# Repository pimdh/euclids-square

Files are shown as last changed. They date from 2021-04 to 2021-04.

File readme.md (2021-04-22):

# Euclid's Square

**THIS IS A WORK IN PROGRESS**

A drum sequencer and sampler based on layering multiple Euclidean rythms. Both firmware and PCB design files are open source licensed under the Creative Commons Attribution 4.0 International License.

## Hardware
It runs on a STM32F722 microcontroller on a custom PCB board.

## Software
The drum machine in written in embedded bare-metal Rust, based on the RTIC framework.

## Samples
Currently, the sampler using the following samples, all in the public domain:
- Hihat https://freesound.org/people/TheFlakesMaster/sounds/399897/
- Snare https://freesound.org/people/alexthegr81/sounds/212208/
- Kick https://freesound.org/people/Mattc90/sounds/351917/

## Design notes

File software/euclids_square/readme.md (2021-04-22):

# Euclid's Square Firmware

Embedded Rust running on a STM32F722. Based on RTIC.

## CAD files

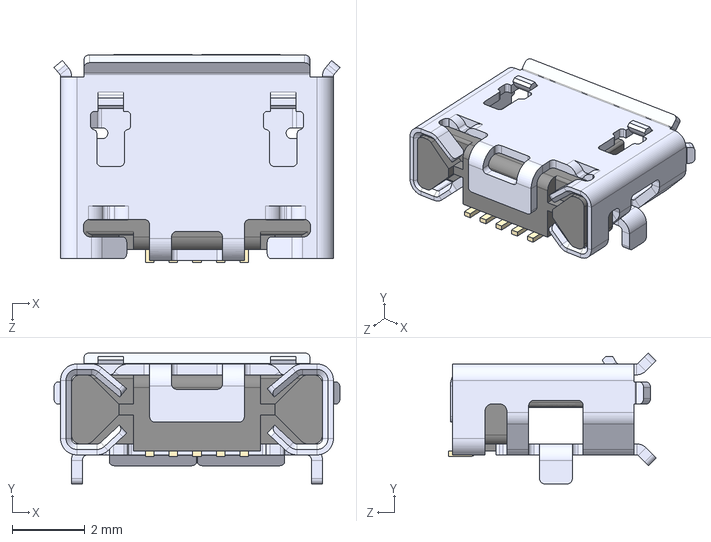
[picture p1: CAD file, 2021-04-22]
hardware/components/10118193-0001LF/10118193-0001LF.step
7.86 x 3.60 x 5.71 mm

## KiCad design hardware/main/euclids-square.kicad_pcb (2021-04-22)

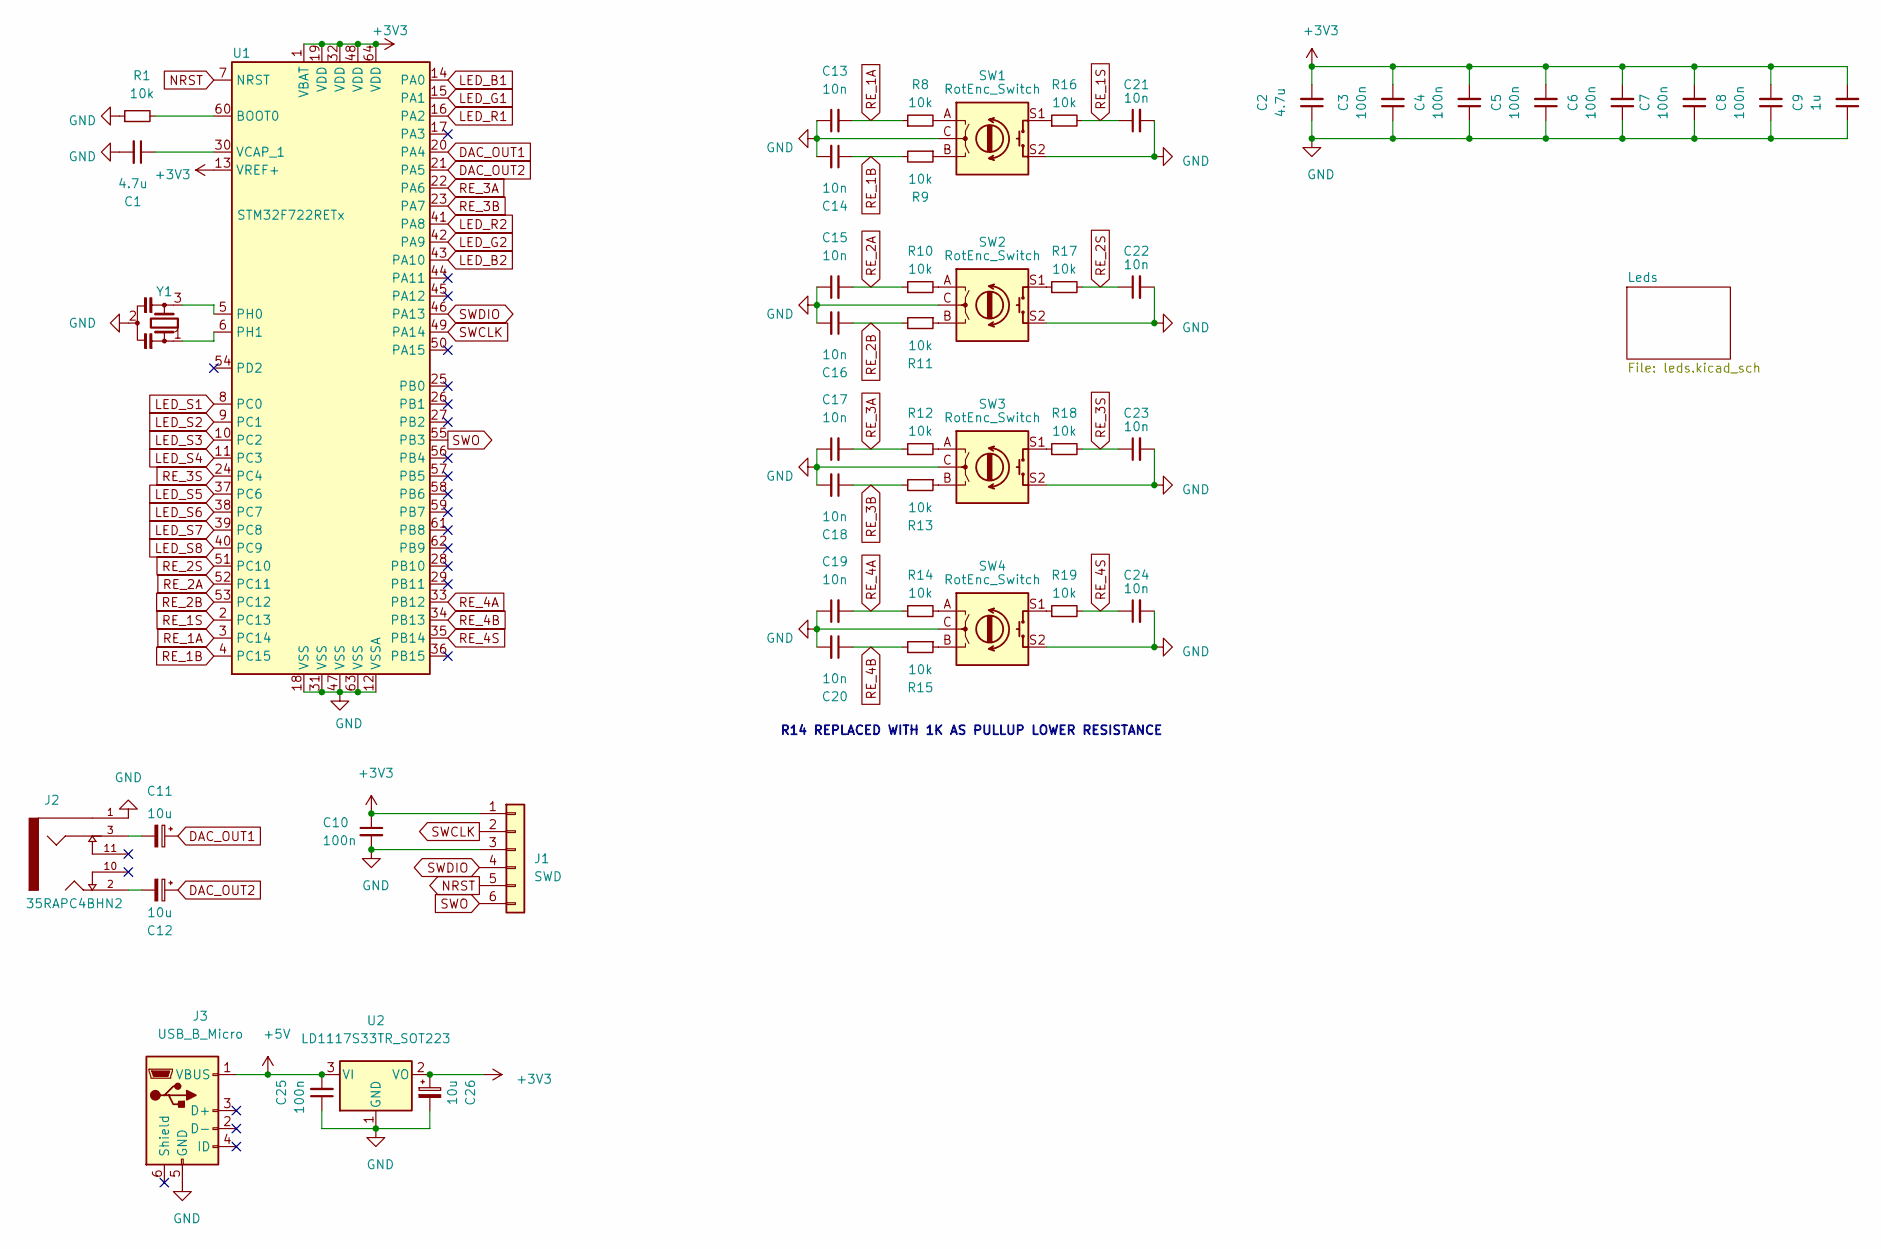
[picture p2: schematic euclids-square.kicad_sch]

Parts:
C1, C2: 4.7u; C_0603_1608Metric; Farnell 3013399
C3, C4, C5, C6, C7, C8, C10, C25: 100n; C_0603_1608Metric; Farnell 2581045
C9: 1u; C_0603_1608Metric; Farnell 3013384
C11, C12, C26: 10u; CP_Elec_4x5.4; Farnell 2611355
C13, C14, C15, C16, C17, C18, C19, C20, C21, C22, C23, C24: 10n; C_0603_1608Metric; Farnell 2496828
J1: SWD; PinHeader_1x06_P2.54mm_Vertical
J2: 35RAPC4BHN2; SWITCHCRAFT_35RAPC4BHN2
J3: USB_B_Micro; USB_Micro-B_Amphenol_10118194_Horizontal
R1, R8, R9, R10, R11, R12, R13, R14, R15, R16, R17, R18, R19: 10k; R_0603_1608Metric; Farnell 2670595
SW1, SW2, SW3, SW4: RotEnc_Switch; RotaryEncoder_Alps_EC12E-Switch_Vertical_H20mm; Farnell 2663527
U1: STM32F722RETx; LQFP-64_10x10mm_P0.5mm; Farnell 3365373
U2: LD1117S33TR_SOT223; SOT-223-3_TabPin2; Farnell 1202826
Y1: Resonator_Small; Resonator_SMD-3Pin_3.2x1.3mm; Farnell 3501598

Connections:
+3V3: C2.2, C3.2, C4.2, C5.2, C6.2, C7.2, C8.2, C9.2, C10.1, C26.1, J1.1, U1.1 (VBAT), U1.13 (VREF+), U1.19 (VDD), U1.32 (VDD), U1.48 (VDD), U1.64 (VDD), U2.2 (VO)
+5V: C25.2, J3.1 (VBUS), U2.3 (VI)
DAC_OUT1: C11.1, U1.20 (PA4)
DAC_OUT2: C12.1, U1.21 (PA5)
GND: C1.2, C2.1, C3.1, C4.1, C5.1, C6.1, C7.1, C8.1, C9.1, C10.2, C13.1, C14.2, C15.1, C16.2, C17.1, C18.2, C19.1, C20.2, C21.2, C22.2, C23.2, C24.2, C25.1, C26.2, J1.3, J2.1, J3.5 (GND), R1.1, SW1.C, SW1.S2, SW2.C, SW2.S2, SW3.C, SW3.S2, SW4.C, SW4.S2, U1.12 (VSSA), U1.18 (VSS), U1.31 (VSS), U1.47 (VSS), U1.63 (VSS), U2.1 (GND), Y1.2; also elsewhere on the board
LED_B1: U1.14 (PA0); also elsewhere on the board
LED_B2: U1.43 (PA10); also elsewhere on the board
LED_G1: U1.15 (PA1); also elsewhere on the board
LED_G2: U1.42 (PA9); also elsewhere on the board
LED_R1: U1.16 (PA2); also elsewhere on the board
LED_R2: U1.41 (PA8); also elsewhere on the board
LED_S1: U1.8 (PC0); also elsewhere on the board
LED_S2: U1.9 (PC1); also elsewhere on the board
LED_S3: U1.10 (PC2); also elsewhere on the board
LED_S4: U1.11 (PC3); also elsewhere on the board
LED_S5: U1.37 (PC6); also elsewhere on the board
LED_S6: U1.38 (PC7); also elsewhere on the board
LED_S7: U1.39 (PC8); also elsewhere on the board
LED_S8: U1.40 (PC9); also elsewhere on the board
NRST: J1.5, U1.7 (NRST)
unnamed: C1.1, U1.30 (VCAP_1)
unnamed: C11.2, J2.3
unnamed: C12.2, J2.2
unnamed: R1.2, U1.60 (BOOT0)
unnamed: R8.2, SW1.A
unnamed: R9.1, SW1.B
unnamed: R10.2, SW2.A
unnamed: R11.1, SW2.B
unnamed: R12.2, SW3.A
unnamed: R13.1, SW3.B
unnamed: R14.2, SW4.A
unnamed: R15.1, SW4.B
unnamed: R16.1, SW1.S1
unnamed: R17.1, SW2.S1
unnamed: R18.1, SW3.S1
unnamed: R19.1, SW4.S1
unnamed: U1.5 (PH0), Y1.3
unnamed: U1.6 (PH1), Y1.1
RE_1A: C13.2, R8.1, U1.3 (PC14)
RE_1B: C14.1, R9.2, U1.4 (PC15)
RE_1S: C21.1, R16.2, U1.2 (PC13)
RE_2A: C15.2, R10.1, U1.52 (PC11)
RE_2B: C16.1, R11.2, U1.53 (PC12)
RE_2S: C22.1, R17.2, U1.51 (PC10)
RE_3A: C17.2, R12.1, U1.22 (PA6)
RE_3B: C18.1, R13.2, U1.23 (PA7)
RE_3S: C23.1, R18.2, U1.24 (PC4)
RE_4A: C19.2, R14.1, U1.33 (PB12)
RE_4B: C20.1, R15.2, U1.34 (PB13)
RE_4S: C24.1, R19.2, U1.35 (PB14)
SWCLK: J1.2, U1.49 (PA14)
SWDIO: J1.4, U1.46 (PA13)
SWO: J1.6, U1.55 (PB3)
no_connect_68: J2.10
no_connect_69: J2.11
no_connect_70: J3.2 (D-)
no_connect_71: J3.3 (D+)
no_connect_72: J3.4 (ID)
no_connect_73: J3.6 (Shield)
no_connect_74: U1.17 (PA3)
no_connect_75: U1.25 (PB0)
no_connect_76: U1.26 (PB1)
no_connect_77: U1.27 (PB2)
no_connect_78: U1.28 (PB10)
no_connect_79: U1.29 (PB11)
no_connect_80: U1.36 (PB15)
no_connect_81: U1.44 (PA11)
no_connect_82: U1.45 (PA12)
no_connect_83: U1.50 (PA15)
no_connect_84: U1.54 (PD2)
no_connect_85: U1.56 (PB4)
no_connect_86: U1.57 (PB5)
no_connect_87: U1.58 (PB6)
no_connect_88: U1.59 (PB7)
no_connect_89: U1.61 (PB8)
no_connect_90: U1.62 (PB9)

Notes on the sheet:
R14 REPLACED WITH 1K AS PULLUP LOWER RESISTANCE

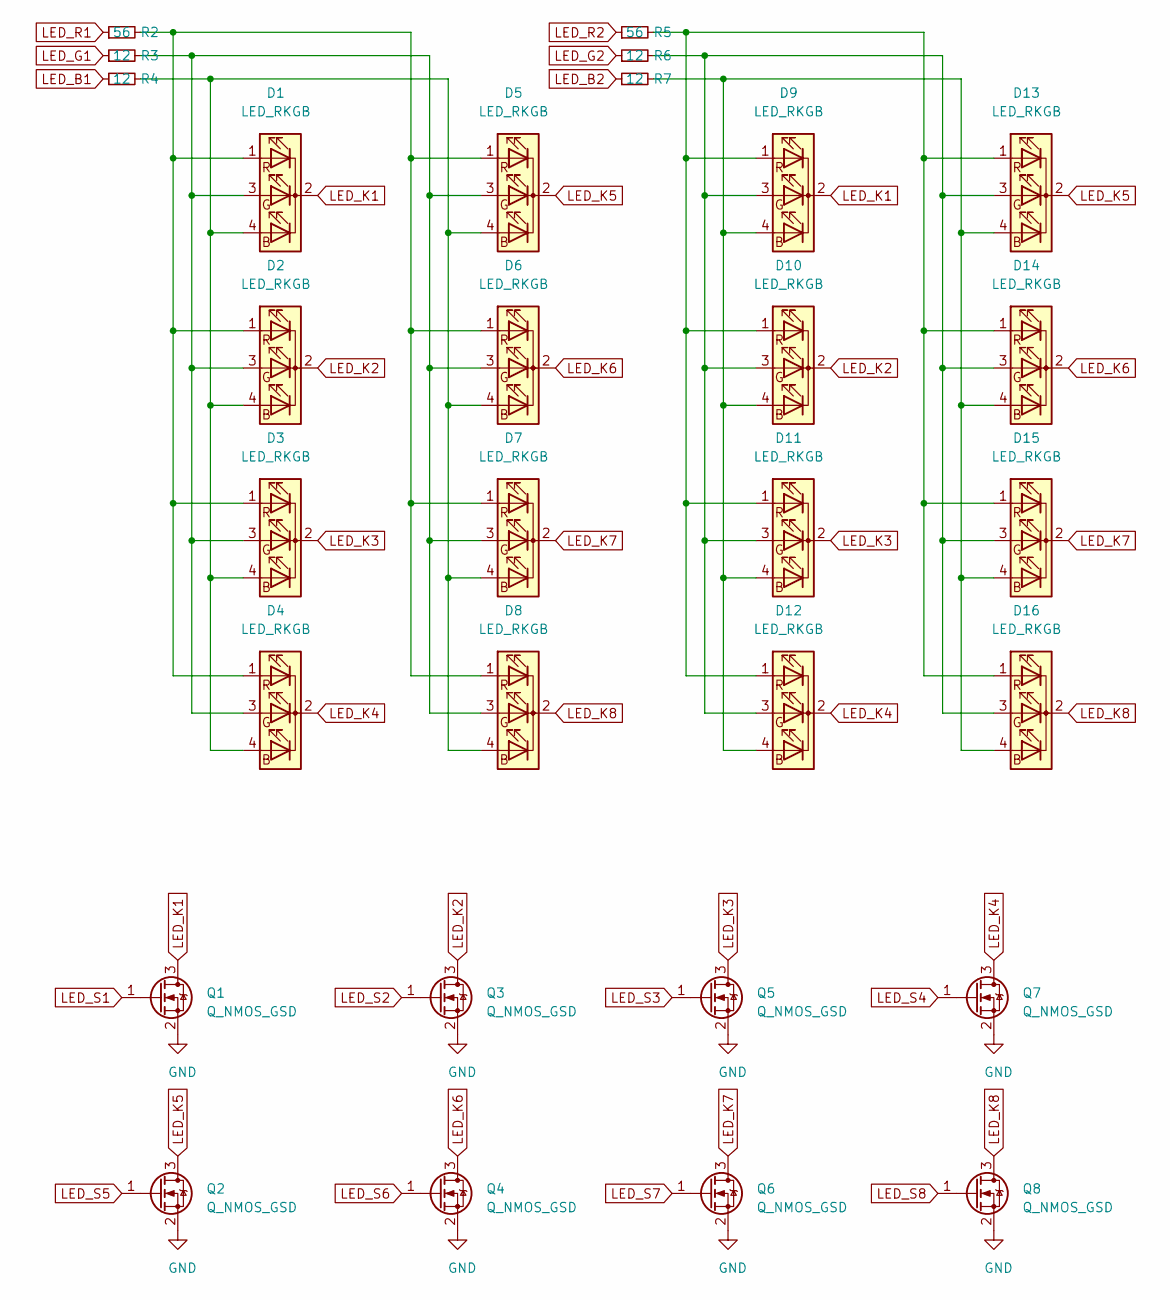
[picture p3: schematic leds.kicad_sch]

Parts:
D1, D2, D3, D4, D5, D6, D7, D8, D9, D10, D11, D12, D13, D14, D15, D16: LED_RKGB; LED_D5.0mm-4_RGB
Q1, Q2, Q3, Q4, Q5, Q6, Q7, Q8: Q_NMOS_GSD; SOT-323_SC-70_Handsoldering; Farnell 3619748
R2, R5: 56; R_0603_1608Metric; Farnell 3540045
R3, R4, R6, R7: 12; R_0603_1608Metric; Farnell 2670626

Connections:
GND: Q1.2 (S), Q2.2 (S), Q3.2 (S), Q4.2 (S), Q5.2 (S), Q6.2 (S), Q7.2 (S), Q8.2 (S); also elsewhere on the board
LED_B1: R4.1; also elsewhere on the board
LED_B2: R7.1; also elsewhere on the board
LED_G1: R3.1; also elsewhere on the board
LED_G2: R6.1; also elsewhere on the board
LED_K1: D1.2 (K), D9.2 (K), Q1.3 (D)
LED_K2: D2.2 (K), D10.2 (K), Q3.3 (D)
LED_K3: D3.2 (K), D11.2 (K), Q5.3 (D)
LED_K4: D4.2 (K), D12.2 (K), Q7.3 (D)
LED_K5: D5.2 (K), D13.2 (K), Q2.3 (D)
LED_K6: D6.2 (K), D14.2 (K), Q4.3 (D)
LED_K7: D7.2 (K), D15.2 (K), Q6.3 (D)
LED_K8: D8.2 (K), D16.2 (K), Q8.3 (D)
LED_R1: R2.1; also elsewhere on the board
LED_R2: R5.1; also elsewhere on the board
LED_S1: Q1.1 (G); also elsewhere on the board
LED_S2: Q3.1 (G); also elsewhere on the board
LED_S3: Q5.1 (G); also elsewhere on the board
LED_S4: Q7.1 (G); also elsewhere on the board
LED_S5: Q2.1 (G); also elsewhere on the board
LED_S6: Q4.1 (G); also elsewhere on the board
LED_S7: Q6.1 (G); also elsewhere on the board
LED_S8: Q8.1 (G); also elsewhere on the board
unnamed: D1.1 (RA), D2.1 (RA), D3.1 (RA), D4.1 (RA), D5.1 (RA), D6.1 (RA), D7.1 (RA), D8.1 (RA), R2.2
unnamed: D1.3 (GA), D2.3 (GA), D3.3 (GA), D4.3 (GA), D5.3 (GA), D6.3 (GA), D7.3 (GA), D8.3 (GA), R3.2
unnamed: D1.4 (BA), D2.4 (BA), D3.4 (BA), D4.4 (BA), D5.4 (BA), D6.4 (BA), D7.4 (BA), D8.4 (BA), R4.2
unnamed: D9.1 (RA), D10.1 (RA), D11.1 (RA), D12.1 (RA), D13.1 (RA), D14.1 (RA), D15.1 (RA), D16.1 (RA), R5.2
unnamed: D9.3 (GA), D10.3 (GA), D11.3 (GA), D12.3 (GA), D13.3 (GA), D14.3 (GA), D15.3 (GA), D16.3 (GA), R6.2
unnamed: D9.4 (BA), D10.4 (BA), D11.4 (BA), D12.4 (BA), D13.4 (BA), D14.4 (BA), D15.4 (BA), D16.4 (BA), R7.2

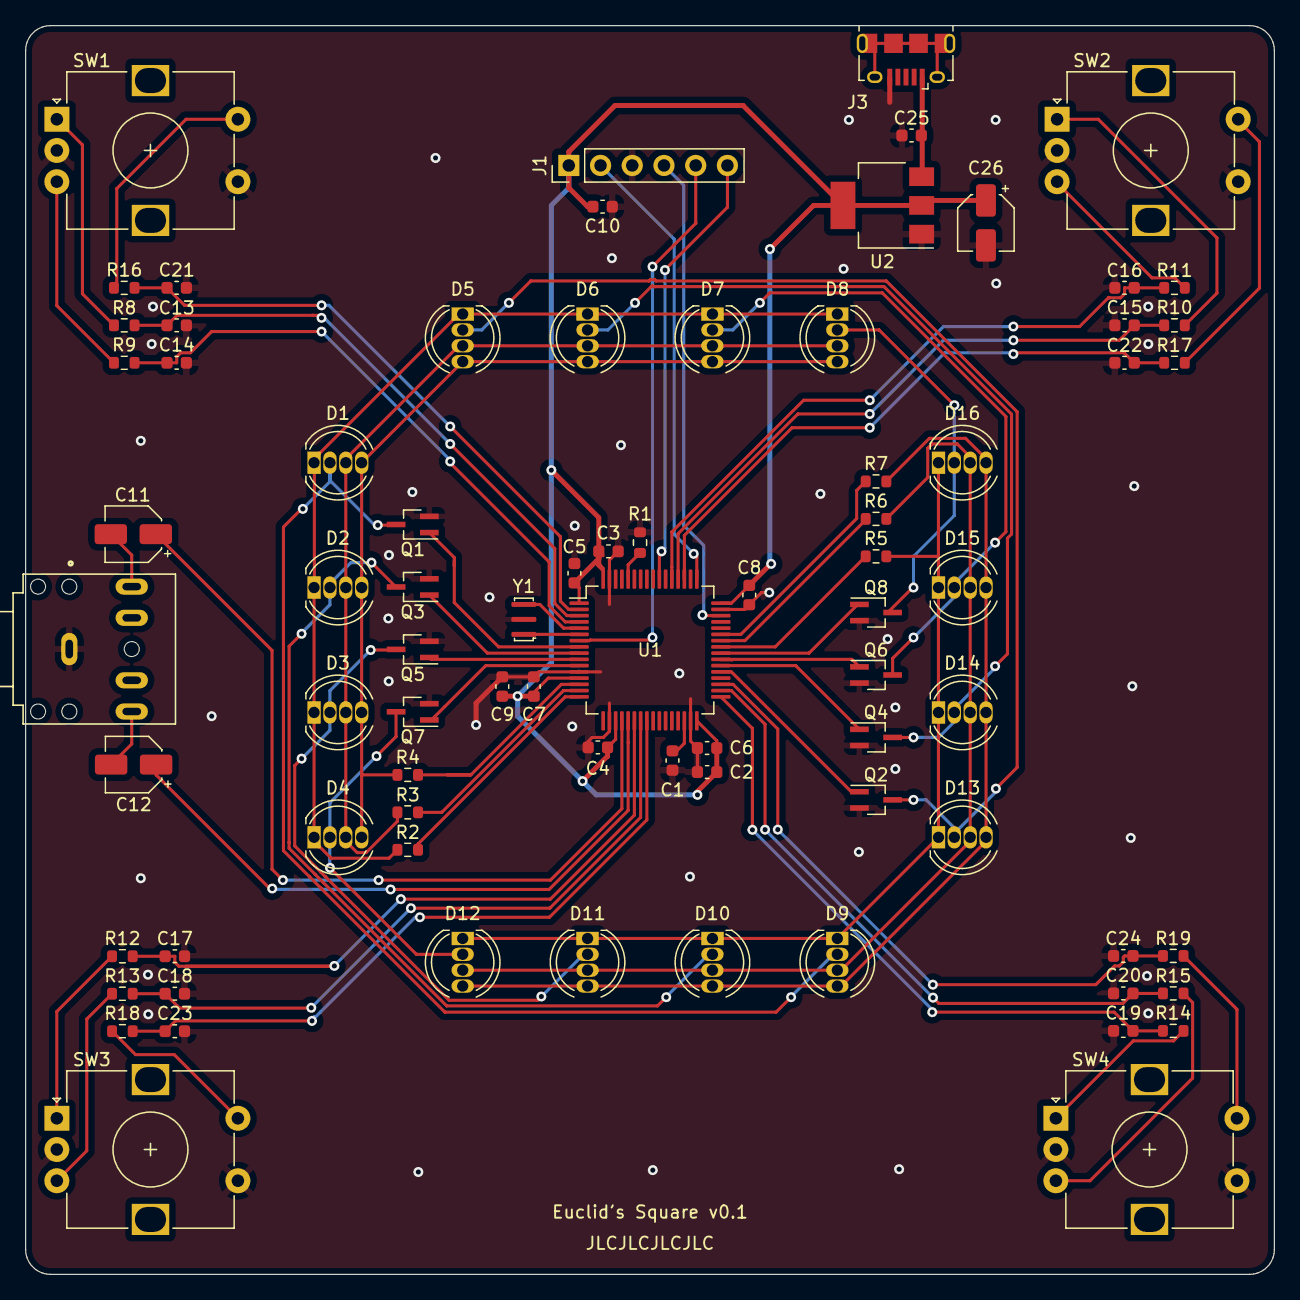
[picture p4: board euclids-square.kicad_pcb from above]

Board: 2 copper layers, 100.0 x 100.0 mm, 79 parts (0 on the bottom side), 67 nets.

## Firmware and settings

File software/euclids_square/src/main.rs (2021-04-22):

#![no_main]
#![no_std]

extern crate cortex_m_rt as rt;
extern crate stm32f7;

extern crate panic_itm;
use rtic::app;
use cortex_m::{iprintln, peripheral::ITM};
use stm32f7::stm32f7x2::Peripherals;
use stm32f7::stm32f7x2::{GPIOA, GPIOB, GPIOC, GPIOE, DMA1, DAC, TIM1, TIM3, TIM4, TIM5, TIM6};
use core::mem;

mod synthesizer;
mod sequencer;
mod leds;
mod init_peripherals;
mod inputs;
mod ui;
mod view;

use synthesizer::{BUFFER_LEN, dma_handler, DmaState, Synth, SynthVoice};
use leds::{show_leds_pwm, LedData};
use init_peripherals::{init_peripherals, init_dma1, init_clock};
use sequencer::Sequencer;
use inputs::{Inputs};
use ui::{UiState, OutputEvent};
use view::render;

const NUM_LAYERS: usize = 3;

// We need to pass monotonic = rtic::cyccnt::CYCCNT to use schedule feature fo RTIC
#[app(device = stm32f7::stm32f7x2, peripherals = true, monotonic = rtic::cyccnt::CYCCNT)]
const APP: () = {
    struct Resources {
        auido_buffer: [u32; BUFFER_LEN],
        gpioa: GPIOA,
        gpiob: GPIOB,
        gpioc: GPIOC,
        gpioe: GPIOE,
        dma1: DMA1,
        dac: DAC,
        itm: ITM,
        tim1: TIM1,
        tim3: TIM3,
        tim4: TIM4,
        tim5: TIM5,
        tim6: TIM6,
        led_data: LedData,
        synth: Synth<NUM_LAYERS>,
        sequencer: Sequencer<NUM_LAYERS, 16>,
        inputs: Inputs,
        ui: UiState<NUM_LAYERS>,
    }

    #[init(spawn = [init_dma1_task])]
    fn init(cx: init::Context) -> init::LateResources {
        let mut core = cx.core;
        let mut itm = core.ITM;
        core.DWT.enable_cycle_counter();
        let device: Peripherals = cx.device;

        init_peripherals(&device);
        init_clock(device.RCC);
        cx.spawn.init_dma1_task().unwrap();

        iprintln!(&mut itm.stim[0], "Hello, Euclid!");
        
        let synth = Synth { voices: [SynthVoice::new(0), SynthVoice::new(1), SynthVoice::new(2)]};
        let mut sequencer: Sequencer<3, 16> = Default::default();
        sequencer.set_sequence(0, 16, 1, 0);
        sequencer.set_sequence(1, 16, 0, 0);
        sequencer.set_sequence(2, 16, 0, 0);

        iprintln!(&mut itm.stim[0], "{:?}", sequencer);

        let inputs: Inputs = Default::default();
        let ui: UiState<NUM_LAYERS> = Default::default();

        init::LateResources {
            auido_buffer: [0; BUFFER_LEN],
            gpioa: device.GPIOA,
            gpiob: device.GPIOB,
            gpioc: device.GPIOC,
            gpioe: device.GPIOE,
            dma1: device.DMA1,
            dac: device.DAC,
            itm,
            tim1: device.TIM1,
            tim3: device.TIM3,
            tim4: device.TIM4,
            tim5: device.TIM5,
            tim6: device.TIM6,
            led_data: [0u32; 16],
            synth, 
            sequencer,
            inputs,
            ui,
        }
    }

    #[task(resources=[dma1, dac, auido_buffer])]
    fn init_dma1_task(cx: init_dma1_task::Context) {
        let dma1 = cx.resources.dma1;
        let auido_buffer = cx.resources.auido_buffer;
        let dac = cx.resources.dac;
        init_dma1(dma1, auido_buffer);
        dac.cr.modify(|_, w| w.dmaen1().enabled());
    }

    #[task(binds = DMA1_STREAM5, resources = [dma1, auido_buffer, synth], priority=1)]
    fn dma1_stream5(mut cx: dma1_stream5::Context) {
        let state = dma_handler(cx.resources.dma1, &mut cx.resources.auido_buffer, &mut cx.resources.synth);
        match state {
            DmaState::Error =>  panic!("DMA error"),
            DmaState::Unknown =>  panic!("Unkonwn DMA state"),
            _ => ()
        }
    }

    // Led multiplex timer
    #[task(binds = TIM3, resources=[gpioc, tim1, tim5, led_data, tim3], priority=3)]
    fn tim3(cx: tim3::Context) {
        static mut STEP: u8 = 0;
        let gpioc = cx.resources.gpioc;
        let tim1 = cx.resources.tim1;
        let tim3 = cx.resources.tim3;
        let tim5 = cx.resources.tim5;
        let led_data = cx.resources.led_data;
        tim3.sr.modify(|_, w| w.uif().clear_bit());
        show_leds_pwm(gpioc, tim1, tim5, &led_data, *STEP);
        *STEP = (*STEP + 1) % 8;
    }

    // Sequencer timer
    #[task(binds = TIM4, resources=[sequencer, tim4, synth], priority=1)]
    fn tim4(cx: tim4::Context) {
        let tim4 = cx.resources.tim4;
        tim4.sr.modify(|_, w| w.uif().clear_bit());

        let gates = cx.resources.sequencer.step();
        cx.resources.synth.apply_gates(gates);
    }

    // User interface
    #[task(binds = TIM6_DAC, resources=[tim6, inputs, gpioa, gpiob, gpioc, itm, ui, led_data, sequencer, tim4], priority=1)]
    fn tim6(mut cx: tim6::Context) {
        let tim4 = cx.resources.tim4;
        let tim6 = cx.resources.tim6;
        let inputs = cx.resources.inputs;
        tim6.sr.modify(|_, w| w.uif().clear_bit());
        let itm = cx.resources.itm;
        let ui = cx.resources.ui;
        let sequencer = cx.resources.sequencer;

        let gpioa_read = cx.resources.gpioa.idr.read();
        let gpiob_read = cx.resources.gpiob.idr.read();
        let gpioc_read = cx.resources.gpioc.lock(|gpioc| gpioc.idr.read());
        let input_event = inputs.update(gpioa_read, gpiob_read, gpioc_read);
        let output_events = ui.update(input_event);

        for output_event in output_events {
            match output_event {
                OutputEvent::LayerUpdate (layer, layer_state) => {
                    iprintln!(&mut itm.stim[0], "{} {:?}", layer, layer_state);
                    sequencer.set_sequence(layer, layer_state.length, layer_state.hits, layer_state.shift);
                    // TODO set volume
                },
                OutputEvent::TempoUpdate (tempo) => {
                    // TODO
                },
                OutputEvent::IsPlaying (is_playing) => {
                    tim4.cr1.modify(|_, w| w.cen().bit(is_playing)); 
                    sequencer.reset_steps();
                },
            }

        }

        let new_led_data = render(ui, sequencer);
        cx.resources.led_data.lock(|led_data| {
            let _ = mem::replace(led_data, new_led_data);
        });
    }

    extern "C" {
        fn EXTI1();
    }
};

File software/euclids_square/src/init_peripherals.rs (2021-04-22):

use stm32f7::stm32f7x2::Peripherals;
use stm32f7::stm32f7x2::{DMA1, RCC};
use stm32f7xx_hal::rcc::{RccExt, HSEClock, HSEClockMode, Clocks};
use stm32f7xx_hal::prelude::*;

use crate::synthesizer::SAMPLE_FREQ;


pub fn init_peripherals(device: &Peripherals) {
    device.RCC.ahb1enr.modify(|_, w|
        w.gpioaen().enabled()
         .gpioben().enabled()
         .gpiocen().enabled()
    );
    init_tim2(&device);
    init_dac(&device);
    device.RCC.ahb1enr.modify(|_, w| w.dma1en().enabled());
    init_leds_pwm(&device);
    init_tim1_pwm(&device);
    init_tim5_pwm(&device);
    init_tim3(&device); // Led multiplex timer
    init_tim4(&device); // Sequencer timer
    init_tim6(&device); // Input poll timer
    init_inputs(&device); // Rot enc inputs
}

pub fn init_clock(rcc: RCC) -> Clocks {
    let rcc = rcc.constrain();
    rcc.cfgr
        .hse(HSEClock::new(8.mhz(), HSEClockMode::Oscillator))
        .hclk(216.mhz())
        .pclk1(54.mhz())
        .pclk2(108.mhz())
        .sysclk(216.mhz())
        .freeze()
}

pub fn init_dac(dp: &Peripherals) {
    // enable GPIOA and DAC clocks
    let rcc = &dp.RCC;
    rcc.apb1enr.modify(|_, w| w.dacen().enabled());

    // configure PA04, PA05 (DAC_OUT1 & DAC_OUT2) as analog, floating
    let gpioa = &dp.GPIOA;
    gpioa.moder.modify(|_, w|
        w.moder4().analog()
         .moder5().analog());
    gpioa.pupdr.modify(|_, w|
        w.pupdr4().floating()
         .pupdr5().floating());

    // configure DAC
    let dac = &dp.DAC;
    dac.cr.modify(|_, w|
        w.boff1().disabled()     // disable dac output buffer for channel 1
         .boff2().disabled()     // disable dac output buffer for channel 2
         .ten1().enabled()       // enable trigger for channel 1
         .ten2().enabled()       // enable trigger for channel 2
         .tsel1().tim2_trgo()    // set trigger for channel 1 to TIM2
         .tsel2().tim2_trgo());  // set trigger for channel 2 to TIM2

    // enable DAC
    dac.cr.modify(|_, w|
        w.en1().enabled()    // enable dac channel 1
         .en2().enabled());  // enable dac channel 2
}

pub fn init_dma1(dma1: &DMA1, buffer: &[u32]) {
    let pa = 0x40007420; // Dual DAC 12-bit right-aligned data holding register (DHR12RD)
    let ma = buffer.as_ptr() as u32;
    let stream = &dma1.st[5];
    stream.par.modify(|_, w| w.pa().bits(pa));     // destination peripheral address
    stream.m0ar.modify(|_, w| w.m0a().bits(ma));  // source memory address
    stream.ndtr.modify(|_, w| w.ndt().bits(buffer.len() as u16));  // number of items to transfer
    stream.cr.modify(|_, w| w.chsel().bits(0b0111));  // Set channel 7 = DAC1
    stream.cr.modify(|_, w| w.pl().high());  // High priority
    stream.fcr.modify(|_, w| w.dmdis().enabled());  // Enable direct mode
    stream.cr.modify(|_, w|
        w.dir().memory_to_peripheral()
         .mburst().single()
         .minc().incremented()  // increment memory address every transfer
         .pinc().fixed()        // don't increment peripheral address every transfer
         .msize().bits32()      // memory word size is 32 bits
         .psize().bits32()      // peripheral word size is 32 bits
         .circ().enabled()      // dma mode is circular
         .teie().enabled()      // trigger an interrupt if an error occurs
         .tcie().enabled()      // trigger an interrupt when transfer is complete
         .htie().enabled()      // trigger an interrupt when half the transfer is complete
    );
    stream.cr.modify(|_, w| w.en().enabled());
}

pub fn init_leds_pwm(dp: &Peripherals) {
    dp.GPIOA.moder.modify(|_, w|
        w.moder0().alternate()
         .moder1().alternate()
         .moder2().alternate()
         .moder8().alternate()
         .moder9().alternate()
         .moder10().alternate()
    );
    dp.GPIOA.afrl.modify(|_, w|
        w.afrl0().af2()  // TIM5 CH1
         .afrl1().af2()  // TIM5 CH2
         .afrl2().af2()  // TIM5 CH3
    );
    dp.GPIOA.afrh.modify(|_, w|
        w.afrh8().af1()  // TIM1 CH1
         .afrh9().af1()  // TIM1 CH2
         .afrh10().af1()  // TIM1 CH3
    );
    
    dp.GPIOC.moder.modify(|_, w| {
        w.moder0().output()
         .moder1().output()
         .moder2().output()
         .moder3().output()
         .moder6().output()
         .moder7().output()
         .moder8().output()
         .moder9().output()
    });
}

pub fn init_inputs(dp: &Peripherals) {
    dp.GPIOA.moder.modify(|_, w|
        w.moder6().input()
         .moder7().input()
    );
    dp.GPIOA.pupdr.modify(|_, w|
        w.pupdr6().pull_up()
         .pupdr7().pull_up()
    );

    dp.GPIOB.moder.modify(|_, w|
        w.moder12().input()
         .moder13().input()
         .moder14().input()
    );
    dp.GPIOB.pupdr.modify(|_, w|
        w.pupdr12().pull_up()
         .pupdr13().pull_up()
         .pupdr14().pull_up()
    );

    dp.GPIOC.moder.modify(|_, w|
        w.moder4().input()
         .moder10().input()
         .moder11().input()
         .moder12().input()
         .moder13().input()
         .moder14().input()
         .moder15().input()
    );
    dp.GPIOC.pupdr.modify(|_, w|
        w.pupdr4().pull_up()
         .pupdr10().pull_up()
         .pupdr11().pull_up()
         .pupdr12().pull_up()
         .pupdr13().pull_up()
         .pupdr14().pull_up()
         .pupdr15().pull_up()
    );
}

pub fn init_tim1_pwm(dp: &Peripherals) {
    // PWM timer for R2, G2, B2
    // Base clock is 216 MHz
    let rcc = &dp.RCC;
    rcc.apb2enr.modify(|_, w| w.tim1en().enabled());

    let arr = 255;
    let tim1 = &dp.TIM1;

    // Setup timer
    tim1.psc.modify(|_, w| w.psc().bits(1));        // Set prescaler to 2 to set base to 54 MHz
    tim1.arr.modify(|_, w| w.arr().bits(arr));      // timer period (sysclk / fs)
    tim1.cr1.modify(|_, w| w.cen().enabled());

    // Setup channels
    tim1.ccmr1_output().modify(|_, w| w.oc1m().pwm_mode1().oc1pe().set_bit()); // Channel 1, PWM mode 1
    tim1.ccmr1_output().modify(|_, w| w.oc2m().pwm_mode1().oc2pe().set_bit()); // Channel 1, PWM mode 1
    tim1.ccmr2_output().modify(|_, w| w.oc3m().pwm_mode1().oc3pe().set_bit()); // Channel 1, PWM mode 1

    tim1.ccer.modify(|_, w| w.cc1e().set_bit());  // enable timer
    tim1.ccer.modify(|_, w| w.cc2e().set_bit());  // enable timer
    tim1.ccer.modify(|_, w| w.cc3e().set_bit());  // enable timer

    tim1.bdtr.modify(|_, w| w.moe().set_bit());
    tim1.egr.write(|w| w.ug().update());  // Update
}
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
